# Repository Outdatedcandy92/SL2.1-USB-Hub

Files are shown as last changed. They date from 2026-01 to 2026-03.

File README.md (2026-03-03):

# SL2.1S USB Hub

A compact USB 2.0 hub that uses the SL2.1S and MCP2221AxML. The board features 1 USB Type-C upstream port and 8 downstream ports with 4 Type-A and 4 Type-C ports, Two of the Type-A ports act as a UART-to-USB and I2C-to-USB bridge.

To use this USB Hub, simply plug the USB-C port that's on the right side to your host device. This USB Hub requires no firmware or drivers and should work by default on all operating systems.





---

## Schematics

The project's KiCad files can be found under `/PCB/kicad`.



---

## PCB



---

## BOM

| Name | Description | Quantity | Price  | Shipping  |
| --- | --- | --- | --- | --- |
| Componenets | Componenets from LCSC. detailed part breakdown [here](/production/bom.csv) | - | $10.40 | $12.64+$3 |
| PCB+Stencil | PCB and Stencil from JLCPCB | - | $7 | $8.84 |
| **Sub Total** | | | $17.40 | $24.48 |
| **Total** | | | $41.88 | |

---

## License

This project is licensed under the CERN Open Hardware Licence Version 2 Weakly Reciprocal [(CERN OHL W)](LICENSE.txt)

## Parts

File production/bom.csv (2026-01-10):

Reference | Qty | Value | LCSC Part | Footprint
C1,C3,C15,C17 | 4 | 10uF | C315248 | Capacitor_SMD:C_0402_1005Metric
C2,C4,C16,C18 | 4 | 100nF | C1525 | Capacitor_SMD:C_0402_1005Metric
C5,C6,C7,C8,C10,C11,C12,C13,C14,C19,C20 | 11 | 1uF | C14445 | Capacitor_SMD:C_0402_1005Metric
D1,D2,D3,D4,D5,D6 | 6 | LED | C20608784 | LED_SMD:LED_0402_1005Metric
H1,H2,H3,H4 | 4 | MountingHole_Pad_MP |  | MountingHole:MountingHole_2.5mm_Pad_TopBottom
J1,J2,J3,J4 | 4 | USB_A | C668591 | easyeda2kicad:USB-A-TH_10.0QHHTZB6.3
R1,R2,R11,R12,R13,R14,R15,R16 | 8 | 5.1K | C25905 | Resistor_SMD:R_0402_1005Metric
R3,R4,R5,R6,R7,R8,R9,R10 | 8 | 56K | C25796 | Resistor_SMD:R_0402_1005Metric
SW1 | 1 | SW_Push_45deg | - | Resistor_SMD:R_0402_1005Metric
U1,U2 | 2 | SL2.1S | C2684433 | easyeda2kicad:SSOP-16_L4.6-W2.6-P0.53-LS4.0-BL
U3 | 1 | MCP2221AxML | C637690 | Package_DFN_QFN:QFN-16-1EP_4x4mm_P0.65mm_EP2.5x2.5mm
USB1,USB2,USB3,USB4,USB5 | 5 | TYPE-C 16PIN 2MD(073) | C2765186 | easyeda2kicad:USB-C-SMD_TYPE-C-6PIN-2MD-073

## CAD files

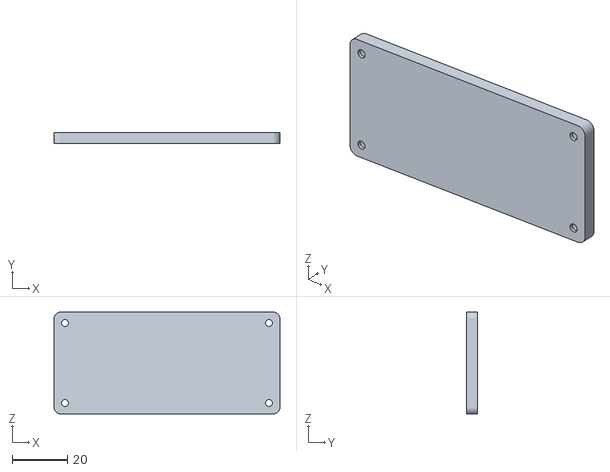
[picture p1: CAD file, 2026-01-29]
case/bottom.stl
82.0 x 4.00 x 37.0

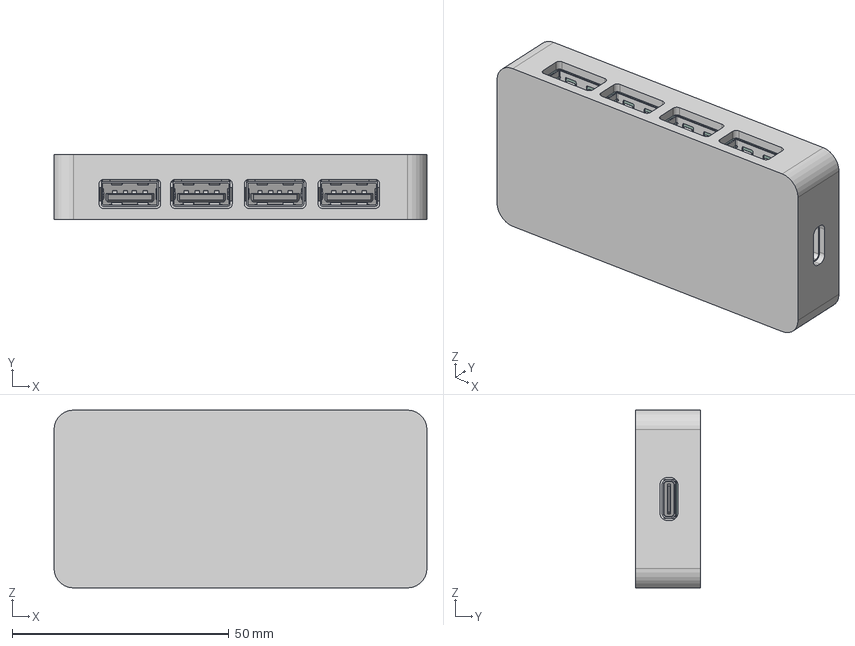
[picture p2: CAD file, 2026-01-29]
case/src/STEP.step
86.0 x 15.0 x 41.0 mm
R_0402_1005Metric x 17
USB-A-TH_10.0QHHTZB6.3 x 4
C_0402_1005Metric x 19
LED_0402_1005Metric x 6
SSOP-16_L4.6-W2.6-P0.53-LS4.0-BL x 2
USB-C-SMD_TYPE-C-6PIN-2MD-073 x 5
QFN-16-1EP_4x4mm_P0.65mm_EP2.5x2.5mm
USB-HUB(SL2.1A)_PCB

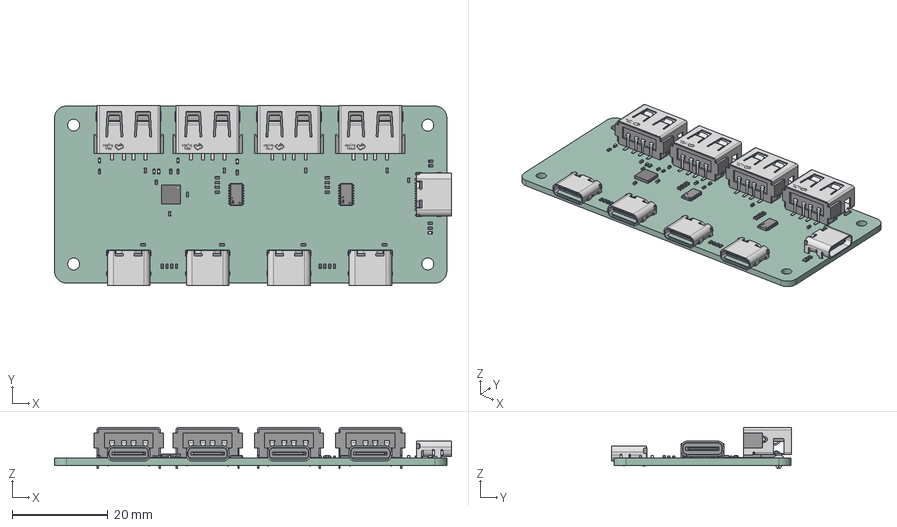
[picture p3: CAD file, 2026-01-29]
PCB/USB-HUB(SL2.1A).step
83.0 x 37.6 x 8.60 mm
R_0402_1005Metric x 17
USB-A-TH_10.0QHHTZB6.3 x 4
C_0402_1005Metric x 19
LED_0402_1005Metric x 6
SSOP-16_L4.6-W2.6-P0.53-LS4.0-BL x 2
USB-C-SMD_TYPE-C-6PIN-2MD-073 x 5
QFN-16-1EP_4x4mm_P0.65mm_EP2.5x2.5mm
USB-HUB(SL2.1A)_PCB

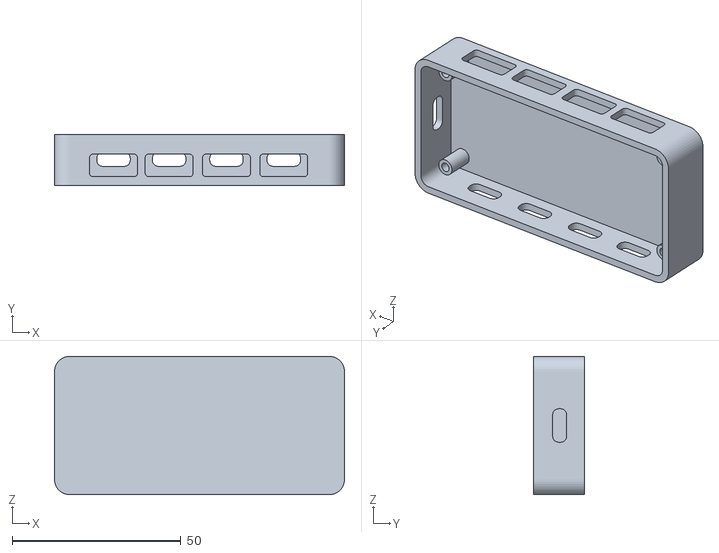
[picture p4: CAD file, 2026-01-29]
case/top.stl
86.0 x 15.0 x 41.0

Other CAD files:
case/src/Fusion360.f3z

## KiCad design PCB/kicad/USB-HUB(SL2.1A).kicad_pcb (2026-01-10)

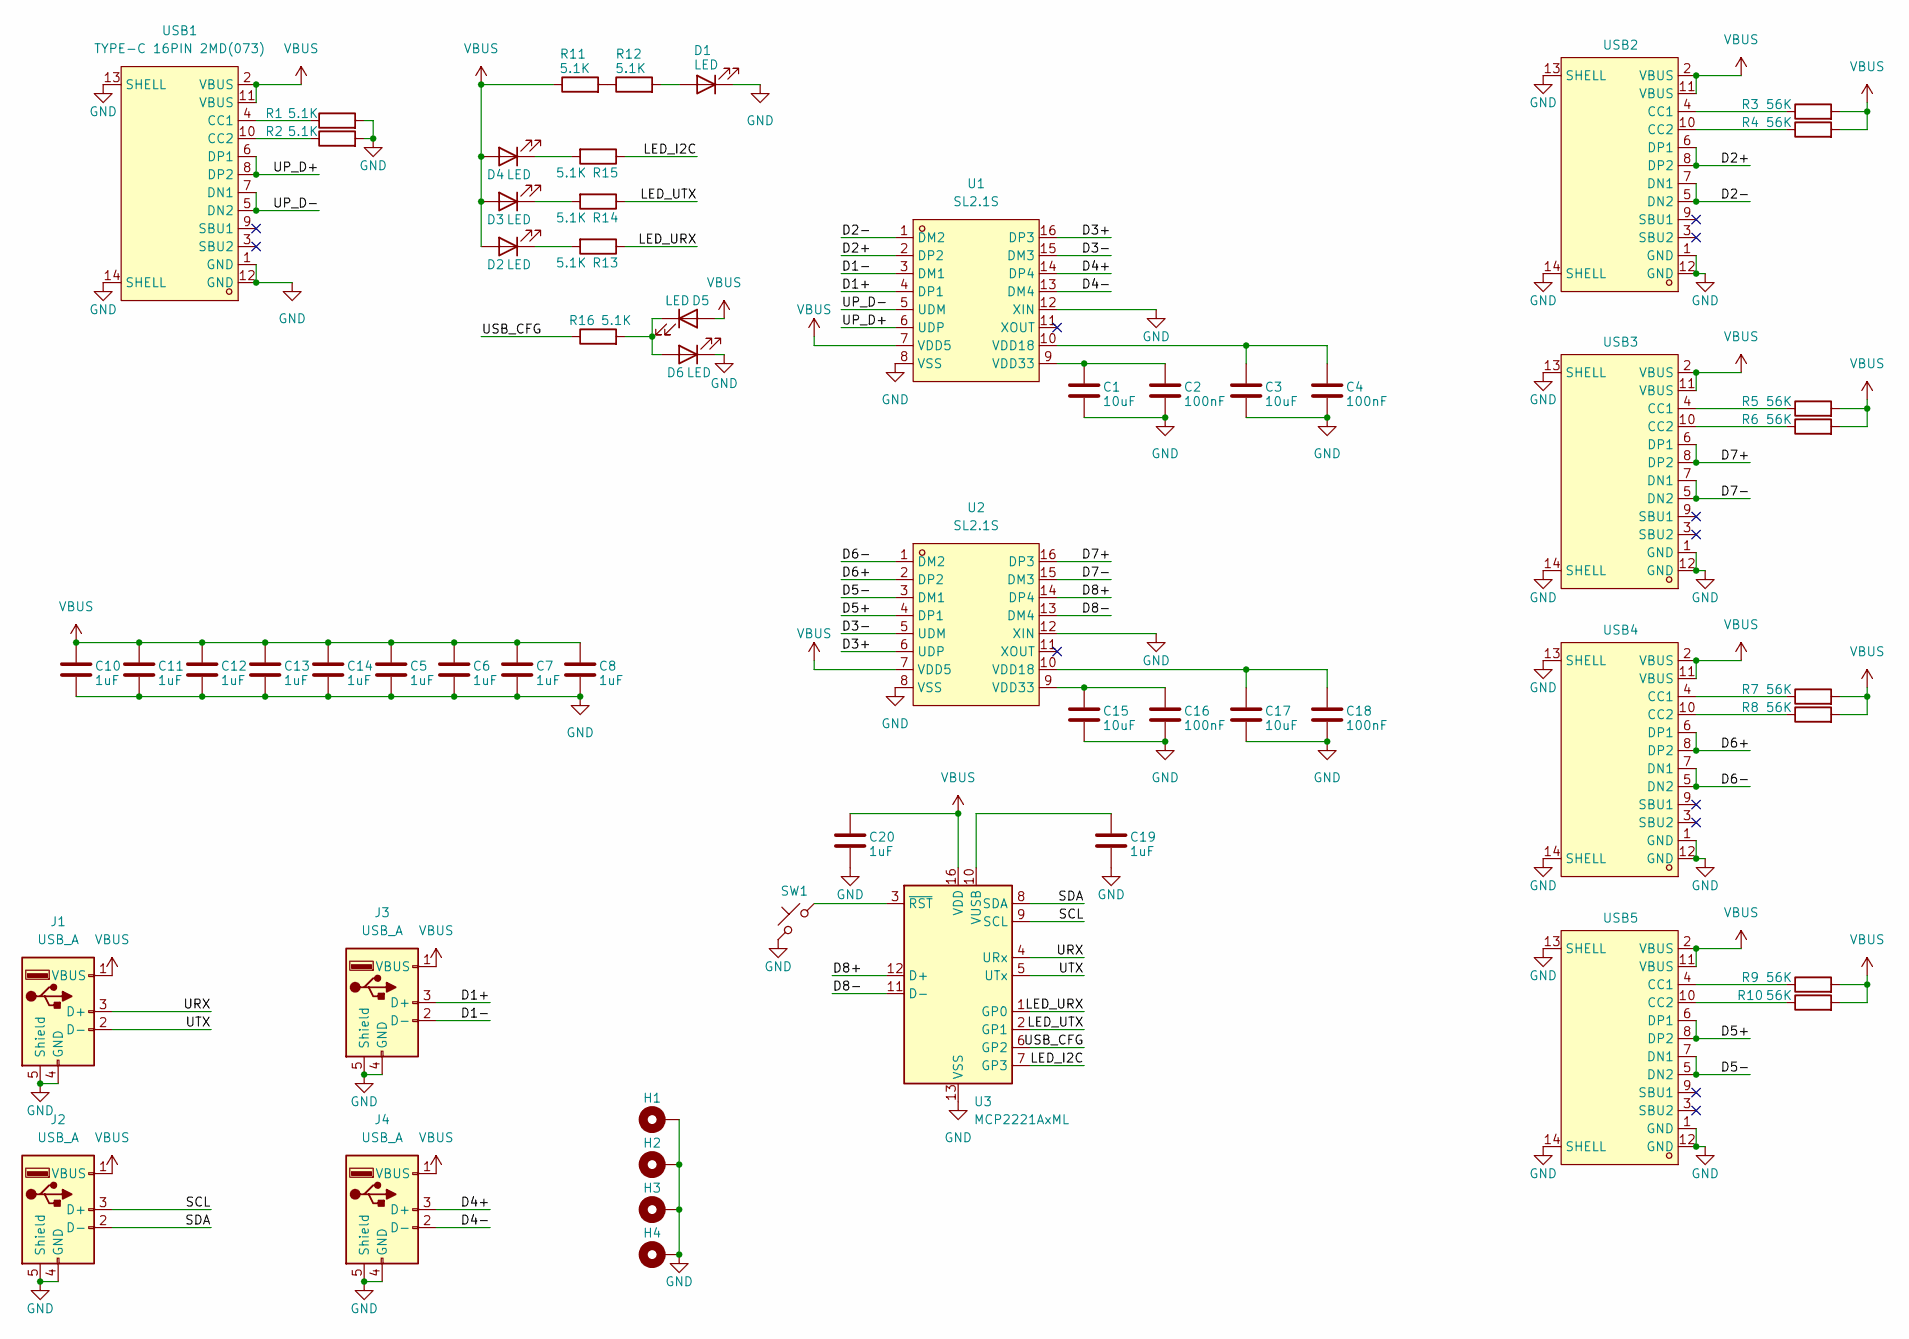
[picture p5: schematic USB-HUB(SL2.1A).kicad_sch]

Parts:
C1, C3, C15, C17: 10uF; C_0402_1005Metric; LCSC Part C315248
C2, C4, C16, C18: 100nF; C_0402_1005Metric; LCSC Part C1525
C5, C6, C7, C8, C10, C11, C12, C13, C14, C19, C20: 1uF; C_0402_1005Metric; LCSC Part C14445
D1, D2, D3, D4, D5, D6: LED; LED_0402_1005Metric; LCSC Part C20608784
H1, H2, H3, H4: MountingHole_Pad_MP; MountingHole_2.5mm_Pad_TopBottom
J1, J2, J3, J4: USB_A; USB-A-TH_10.0QHHTZB6.3; LCSC Part C668591
R1, R2, R11, R12, R13, R14, R15, R16: 5.1K; R_0402_1005Metric; LCSC Part C25905
R3, R4, R5, R6, R7, R8, R9, R10: 56K; R_0402_1005Metric; LCSC Part C25796
SW1: SW_Push_45deg; R_0402_1005Metric
U1, U2: SL2.1S; SSOP-16_L4.6-W2.6-P0.53-LS4.0-BL; LCSC Part C2684433
U3: MCP2221AxML; QFN-16-1EP_4x4mm_P0.65mm_EP2.5x2.5mm; LCSC Part C637690
USB1, USB2, USB3, USB4, USB5: TYPE-C 16PIN 2MD(073); USB-C-SMD_TYPE-C-6PIN-2MD-073; LCSC Part C2765186

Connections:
/D1+: J3.3 (D+), U1.4 (DP1)
/D1-: J3.2 (D-), U1.3 (DM1)
/D2+: U1.2 (DP2), USB2.6 (DP1), USB2.8 (DP2)
/D2-: U1.1 (DM2), USB2.5 (DN2), USB2.7 (DN1)
/D3+: U1.16 (DP3), U2.6 (UDP)
/D3-: U1.15 (DM3), U2.5 (UDM)
/D4+: J4.3 (D+), U1.14 (DP4)
/D4-: J4.2 (D-), U1.13 (DM4)
/D5+: U2.4 (DP1), USB5.6 (DP1), USB5.8 (DP2)
/D5-: U2.3 (DM1), USB5.5 (DN2), USB5.7 (DN1)
/D6+: U2.2 (DP2), USB4.6 (DP1), USB4.8 (DP2)
/D6-: U2.1 (DM2), USB4.5 (DN2), USB4.7 (DN1)
/D7+: U2.16 (DP3), USB3.6 (DP1), USB3.8 (DP2)
/D7-: U2.15 (DM3), USB3.5 (DN2), USB3.7 (DN1)
/D8+: U2.14 (DP4), U3.12 (D+)
/D8-: U2.13 (DM4), U3.11 (D-)
/LED_I2C: R15.1, U3.7 (GP3)
/LED_URX: R13.1, U3.1 (GP0)
/LED_UTX: R14.1, U3.2 (GP1)
/SCL: J2.3 (D+), U3.9 (SCL)
/SDA: J2.2 (D-), U3.8 (SDA)
/UP_D+: U1.6 (UDP), USB1.6 (DP1), USB1.8 (DP2)
/UP_D-: U1.5 (UDM), USB1.5 (DN2), USB1.7 (DN1)
/URX: J1.3 (D+), U3.4 (URx)
/USB_CFG: R16.1, U3.6 (GP2)
/UTX: J1.2 (D-), U3.5 (UTx)
GND: C1.2, C2.2, C3.2, C4.2, C5.2, C6.2, C7.2, C8.2, C10.2, C11.2, C12.2, C13.2, C14.2, C15.2, C16.2, C17.2, C18.2, C19.2, C20.2, D1.1 (K), D6.1 (K), H1.MP, H2.MP, H3.MP, H4.MP, J1.4 (GND), J1.5 (Shield), J2.4 (GND), J2.5 (Shield), J3.4 (GND), J3.5 (Shield), J4.4 (GND), J4.5 (Shield), R1.2, R2.2, SW1.2, U1.8 (VSS), U1.12 (XIN), U2.8 (VSS), U2.12 (XIN), U3.13 (VSS), USB1.1 (GND), USB1.12 (GND), USB1.13 (SHELL), USB1.14 (SHELL), USB2.1 (GND), USB2.12 (GND), USB2.13 (SHELL), USB2.14 (SHELL), USB3.1 (GND), USB3.12 (GND), USB3.13 (SHELL), USB3.14 (SHELL), USB4.1 (GND), USB4.12 (GND), USB4.13 (SHELL), USB4.14 (SHELL), USB5.1 (GND), USB5.12 (GND), USB5.13 (SHELL), USB5.14 (SHELL)
unnamed: D1.2 (A), R12.2
unnamed: D2.1 (K), R13.2
unnamed: D3.1 (K), R14.2
unnamed: D4.1 (K), R15.2
unnamed: D5.1 (K), D6.2 (A), R16.2
unnamed: R11.2, R12.1
unnamed: C3.1, C4.1, U1.10 (VDD18)
unnamed: C1.1, C2.1, U1.9 (VDD33)
unnamed: C17.1, C18.1, U2.10 (VDD18)
unnamed: C15.1, C16.1, U2.9 (VDD33)
unnamed: C19.1, U3.10 (VUSB)
unnamed: SW1.1, U3.3 (~RST)
unnamed: R1.1, USB1.4 (CC1)
unnamed: R2.1, USB1.10 (CC2)
unnamed: R3.1, USB2.4 (CC1)
unnamed: R4.1, USB2.10 (CC2)
unnamed: R5.1, USB3.4 (CC1)
unnamed: R6.1, USB3.10 (CC2)
unnamed: R7.1, USB4.4 (CC1)
unnamed: R8.1, USB4.10 (CC2)
unnamed: R9.1, USB5.4 (CC1)
unnamed: R10.1, USB5.10 (CC2)
VBUS: C5.1, C6.1, C7.1, C8.1, C10.1, C11.1, C12.1, C13.1, C14.1, C20.1, D2.2 (A), D3.2 (A), D4.2 (A), D5.2 (A), J1.1 (VBUS), J2.1 (VBUS), J3.1 (VBUS), J4.1 (VBUS), R3.2, R4.2, R5.2, R6.2, R7.2, R8.2, R9.2, R10.2, R11.1, U1.7 (VDD5), U2.7 (VDD5), U3.16 (VDD), USB1.2 (VBUS), USB1.11 (VBUS), USB2.2 (VBUS), USB2.11 (VBUS), USB3.2 (VBUS), USB3.11 (VBUS), USB4.2 (VBUS), USB4.11 (VBUS), USB5.2 (VBUS), USB5.11 (VBUS)

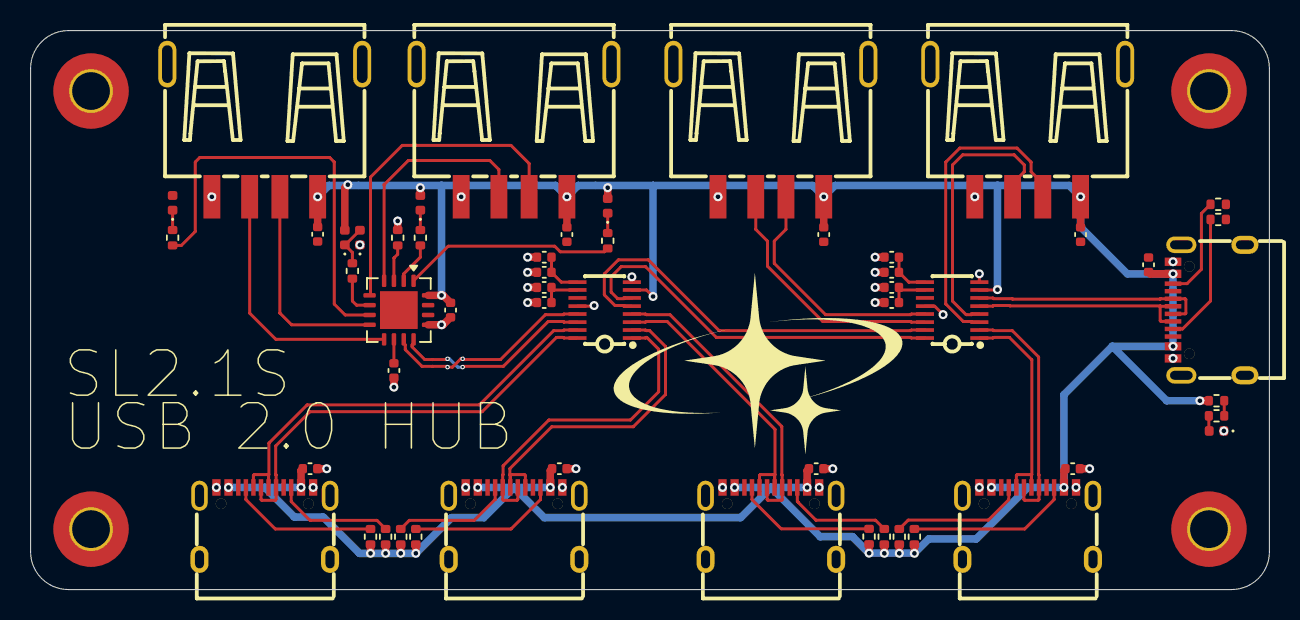
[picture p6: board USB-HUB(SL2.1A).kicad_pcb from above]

Board: 2 copper layers, 82.0 x 37.0 mm, 58 parts (0 on the bottom side), 50 nets.

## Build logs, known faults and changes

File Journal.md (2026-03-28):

# USB Hub

> Some images in the journal are unavailable due to a CDN issue. 

## 27/12/25

I was pretty bored and ran out of ideas today so I decided to speedrun a USB Hub; to be honest I have been in need of a usb hub for a LONG time but always procrastinated making one (since onboard btw).

I decided to use the SL2.1S chip because it's a fairly easy IC to use; requires no external crystals and have 4 downstream facing ports which is good enough for me (though I did spent a lot of time looking at alternatives from microchip and ti but they were too overkill for what I needed). 
I had to first translate the whole datasheet because it was originally in Chinese; the datasheet says that it does require and external crystal to work but I referred to some designs online and they seem to be working fine without one, so I went ahead with my schematics and connected xin to gnd.


I added a 100nf and 1uF capacitor for each power pin (although this was probably not required); after this I went ahead with my PCB design (the fun part!!); started off by assigning net classes and color coding them to give me a better view as usual.



Layout was pretty easy as this PCB hardly had any components; I went with a 50x20mm board to keep the hub as tiny as possible. Here are some pictures of the routing process







^This was the finished board, I went with 2 layers and routed all the data and cc traces on top, poured ground on bottom and routed power; I did make sure to not have any splits in the ground plane under the data pairs!

And another thing I added was a power indicator led; its just a green led connected to the vbus to indicate power detection. For this I added two 5.1k resistors in series to limit current which adds up to 10.2k ohm in series with the LED. Now you may think that this is way to much and that the led would barely glow, but you'd be wrong; 0402 LEDs are super efficient and super bright, even at 10K resistor in series at 5v the LED is bright enough to be seen in a lit room.
Oh and yeah the reason I went with two 5.1k resistors in series instead of just one 10k resistor was to optimize the BOM; even though the project is pretty cheap, why use more components than needed right.



After this I spent a couple of minutes adding some basic silkscreen and assigning lcsc parts; generating the BOM with prices and finally setting up a github repository.



Anywho this is how the final board looks like!



## Time Spent: 3.5 Hours

---

## 9/01/26

Decided to add some more features to the USB hub. I figured why not add an onboard USB to UART chip so I can just use the hub as a debugging tool, and so I began my research and found the MCP2221A.

The MCP2221A is a small USB 2.0 to I2C/UART convertor chip by microchip which came in a small 4x4 QFN package.


I also decided to add another SL2.1S IC and daisy chain it with the first one to get a total of 7 downstream USB ports, out of those 7 downstream ports I used 6 for USB and 1 for the MCP2221.



Wiring up the MCP2221 was pretty straightforward, the datasheet was also helpful and I found that the 4 GPIO pins have a default function as indication for activity and so I wired those up to some LEDs.



Now the UART/I2C indicators go low when they sense activity, but the USB_CFG goes high/low depending on if the USB is successfully configured or in suspend mode.

Moving onto the PCB, it was pretty clear to me that I'd have to start over again, and so I deleted everything I originally had and started fresh with a new layout.



I went with a symmetric layout (kinda) with 4 USB-A ports on one side and 4 USB-C ports on the other side.



After that I just routed everything and fixed the pinouts in the schematics based on which port was the closest, and in the end I ended up with this.





Also decided to add mounting holes on the PCB as you can see, decided I might need them in the future if I plan on making a case. 
Also spent a few minutes just updating the BOM and getting prices from lcsc and JLC.

## Time Spent: 3 Hours

# 22/01/26

I worked on designing a case for the USB Hub today. 

Started off my correcting the 3D model placements in kicad and then exported them into Fusion360.



Now the problem I faced here was that each part was an individual component and I couldn't move them all together at once. I tried saving the board and then importing it into a new project but still I could only individually select components. The solution I found was to assign all these components a rigid body set, that basically makes is so that when you move one component the rest follow.

Now designing the case was pretty straightforward as I aimed to be as minimal as possible.

I started off by designing the bottom plate first, it was a very simple very thin plate with countersunk holes for an M2 screw.



For the top part of the case I just designed a rectangle and then projected the USB port's geometry on it and cut it out with some offset.



Inside the top part I added these 4 pillars type thing inside which I can later fit some heatset M2 inserts to screw onto and secure the bottom plate and PCB.



The finished case look something like this-







## Time Spent: 1.5 Hours

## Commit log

2025-12-28 rev 1
    [USB-HUB(SL2.1A).kicad_pcb, USB-HUB(SL2.1A).kicad_sch, bom.csv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]
2025-12-28 added board .step file
    [USB-HUB(SL2.1A).step]
2026-01-10 rev 2.0
    [USB-HUB(SL2.1A).kicad_pcb, USB-HUB(SL2.1A).kicad_sch, bom.csv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]
2026-01-29 change cdn
    [Fusion360.f3z, STEP.step, USB-HUB(SL2.1A).step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]
